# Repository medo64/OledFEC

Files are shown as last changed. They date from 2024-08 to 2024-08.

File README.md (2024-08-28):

# OLED Framework Expansion Card

Framework computer expansion card that allows a USB CDC serial connection to
SSD1306 OLED display modules.

## Pinout

To connect to this board, one has to use a 4-pin JST XH connector. The following
table represents the pinout, pin 1 being on the left as looking into the
expansion card.

| # | Ref | Description |
|--:|:-----:|---|
| 1 | GND | Ground connection |
| 2 | 5V | OLED power |
| 2 | SCL | I²C clock |
| 3 | SDA | I²C data |

As power consumption is low, wires can be almost any AWG. I would recommend
using 24 AWG wire 0.25 mm² as they allow for greater compatibility with other
connectors.

## LEDs

LED will blink on UART communication with computer (both sending toward and
receiving data from computer).

## Protocol

This driver will present itself to the system as CDC USB device. Communication
protocol is text-based and available [here](https://github.com/medo64/UsbOled.Firmware).

---

*You can check my blog and other projects at [www.medo64.com](https://www.medo64.com/electronics/).*

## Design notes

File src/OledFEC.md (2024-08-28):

## OledFEC Parts

### Properties

| | |
|---|---:|
| Dimensions | 27.4 x 12.0 mm |
| Voltage | 5 V ±10% |
| Current | 200 mA |

### Parts

|  # | Part | RefDes  | DigiKey Part Number |
|---:|---|---|---|
|  1 | C 100nF X7R 16V (0805) | C1 | 478-5311-1-ND |
|  2 | C 1uF 16V X7R (0805) | C2-C3 | 1276-6471-1-ND |
|  1 | DS LED (0805) | DS1 | 475-1415-1-ND |
|  1 | J USB C, plug, straddle 0.8mm | J1 | WM12855-ND |
|  1 | J JST XH Vertical (4w) | J2 | 455-B4B-XH-A-ND |
|  1 | L Ferrite 1A 40Ohm (0805) | L1 | 445-2201-1-ND |
|  1 | R 1K 0.125W (0805) | R1 | RMCF0805FT1K00CT-ND |
|  3 | R 5.1K 0.125W (0805) | R2-R4 | RMCF0805FT5K10CT-ND |
|  1 | U PIC16F1454-I/ST (SSOP-14) | U1 | PIC16F1454-I/ST-ND  |
|  1 | U MIC2091-1 (SOT23-5) | U2 | 576-3891-1-ND |

#### Optional I²C Pull-Up

Jumper JP1 allows you to select if pull-ups are using 3.3V or 5V line.

As OLED display is expected to have a pull-up resistors for I²C line (commonly
`4.7K`), no additional I²C resistors are usually required and therefore this
jumper should be left as-is. If your display works without pull-ups, DO NOT
solder jumper JP1.

If additional I²C pull-ups are needed there are 2 resistor footprints available
on the OLED side pre-populated with `5.1K` pull-ups. Ff `4.7K` pull up is
already available on OLED board, soldering jumper JP1 to either 3.3V or 5V
position will result in `2.45K` pull-up value. Such strong pull up is probably
not necessary but left as an option "just in case".

---

*You can check my blog and other projects at [www.medo64.com](https://www.medo64.com/electronics/)*

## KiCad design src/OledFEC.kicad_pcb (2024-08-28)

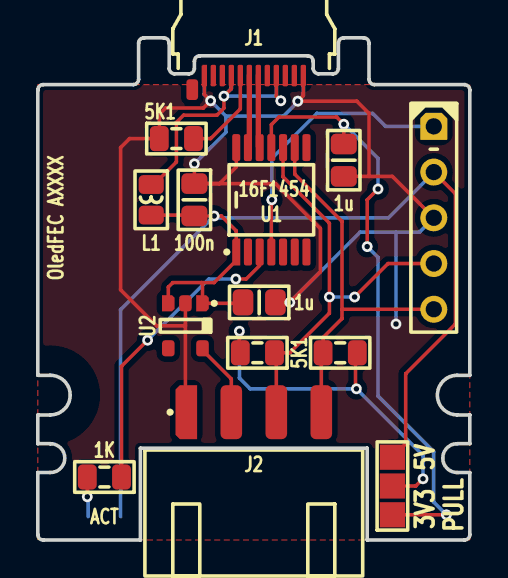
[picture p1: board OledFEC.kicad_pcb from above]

Board: 2 copper layers, 24.0 x 27.9 mm, 15 parts (1 on the bottom side), 14 nets.

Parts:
C1: 100n; C (0805)
C2, C3: 1u; C (0805)
DS1: ACT; DS (0805)
ICSP: Microchip PIC; ICSP PIC Pogo (5w)
J1: 105444-0001; J USB C 3.2 Edge (24w)
J2: B4B-XH-A; J JST XH Edge [OLED] (4w)
JP1: Jumper; JP Dual (1205)
L1: 40R; L (0805)
R1: 1K; R (0805)
R2, R3, R4: 5K1; R (0805)
U1: 16F1454; U Micro [PIC16F1454] (TSSOP-14)
U2: MIC2005A-1; U LoadSwitch 100mA [MIC2091-1] (SOT23-5)

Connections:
3V3: C2.2, JP1.1, U1.11
5V: C1.2, C3.2, DS1.2, ICSP.2, JP1.3, L1.2, U1.1, U2.1, U2.3
5V_USB: J1.A4, J1.A9, J1.B04, J1.B09, L1.1
A_CC: J1.A5, R2.2
GND: C1.1, C2.1, C3.1, ICSP.3, J1.A1, J1.A12, J1.B01, J1.B12, J2.1, R2.1, U1.14, U2.2
ICSP_VPP: ICSP.1, U1.4
LED_ACTIVE: DS1.1, R1.2
OLED_5V: J2.2, U2.5
OLED_SCL: ICSP.4, J2.3, R3.1, U1.10
OLED_SDA: ICSP.5, J2.4, R4.1, U1.9
OUT_LED_ACTIVE: R1.1, U1.3
PULL_UP: JP1.2, R3.2, R4.2
USB_DM: J1.A7, U1.12
USB_DP: J1.A6, U1.13

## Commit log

2024-08-22 Using MIC2091-1 instead of MIC2005A-1
    [OledFEC.kicad_pcb]
2024-08-28 Added pull-up jumper
    [OledFEC.kicad_pcb]
2024-08-28 Updated pull-up resistors to be populated
    [OledFEC.kicad_pcb]
